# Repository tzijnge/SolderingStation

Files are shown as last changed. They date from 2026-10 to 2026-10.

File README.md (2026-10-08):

# SolderingStation

[WIO Terminal](https://wiki.seeedstudio.com/Wio_Terminal_Intro/) adaptation of the [Elektor Platino soldering station](https://www.elektormagazine.com/magazine/elektor-201507/27978)

## Development environment

### Tooling

- [Visual Studio Code](https://code.visualstudio.com/)
- [PlatformIO IDE extension](https://platformio.org/install/ide?install=vscode) for VS Code (recommended in `.vscode/extensions.json`)
  - Installs its own toolchain (GCC ARM, `pio` CLI, etc.) on first use — no separate Arduino IDE or ARM toolchain install needed
- [Teleplot](https://teleplot.fr/) VS Code extension (optional) — for live-plotting the PID tuning telemetry printed over serial, see [Telemetry / PID tuning](#telemetry--pid-tuning) below
- [KiCad 10](https://www.kicad.org/) — for the front panel PCB, see [Front panel](#front-panel) below

### Hardware target

- [Seeed WIO Terminal](https://wiki.seeedstudio.com/Wio_Terminal_Intro/) (SAMD51, Cortex-M4F)
- `atmelsam` platform, `board = seeed_wio_terminal`, `framework = arduino` (see `platformio.ini`)

### Libraries

Declared in `platformio.ini` under `lib_deps`, fetched automatically by PlatformIO on build:

- [LovyanGFX](https://github.com/lovyan03/LovyanGFX) — drives the 2.4" ILI9341 LCD (`#include <LovyanGFX.hpp>`, class `LGFX`), using genuine DMA-based SPI for speed. Needs `-D LGFX_AUTODETECT -D LGFX_WIO_TERMINAL` in `platformio.ini`'s `build_flags`, since PlatformIO's `seeed_wio_terminal` board definition doesn't define `ARDUINO_WIO_TERMINAL`, which LovyanGFX's autodetect normally keys off.
- [SparkFun_Qwiic_Twist_Arduino_Library](https://github.com/sparkfun/SparkFun_Qwiic_Twist_Arduino_Library) — driver for the Qwiic Twist rotary encoder, connected via a Grove-to-Qwiic cable on the WIO Terminal's Grove I2C port
- [ETL (Embedded Template Library)](https://github.com/ETLCPP/etl) — used throughout for containers/utilities in this interrupt-driven design
- [Arduino-PID-Library](https://github.com/br3ttb/Arduino-PID-Library) — drives the tip-temperature PID control loop

### Building and uploading

Build and upload using the PlatformIO sidebar in VS Code (project/build/upload icons in the PlatformIO toolbar), or the equivalent `pio run` / `pio run -t upload` commands from a PlatformIO Core CLI.

### Known build gotchas

- `Arduino.h` `#define`s `round(x)` as a macro, which breaks ETL's `etl::to_string`. Add `#undef round` right after `#include <Arduino.h>` and before any `etl/*` includes in any file that includes both.
- LovyanGFX's rotation numbering for this board is offset by 180° from the old TFT_eSPI-based fork this project used to use — call `tft.setRotation(1)` (not `3`) for correct upright landscape orientation.

## Hardware

### Inputs

- Three onboard buttons (`WIO_KEY_A`/`B`/`C`, pins 28/29/30). Physical left-to-right position does **not** match alphabetical pin naming — confirmed on-device: left = `WIO_KEY_C`, middle = `WIO_KEY_B`, right = `WIO_KEY_A`.
- [SparkFun Qwiic Twist](https://www.sparkfun.com/products/15083) rotary encoder, connected via Grove-to-Qwiic cable into the WIO Terminal's Grove I2C port (standard `Wire`, no special Qwiic-specific setup needed). Its INT pad is wired to `BCM21` (40-pin header physical position 40) — confirmed working. **Do not** wire it to `BCM2` (physical position 3): despite the Arduino pin table labeling it as a free, independent I2C bus, it shares a net at the PCB level with the Grove I2C bus and breaks the Twist's communication when wired, even before any new firmware is uploaded.
  - The Twist library never enables its own interrupt register (`TWIST_ENABLE_INTS`, `0x04`) — `setup()` writes it directly over raw I2C (`0x03`, encoder + button interrupt bits) to get the INT line to assert at all.
  - `twist.setIntTimeout(0)` is set to avoid the default ~250ms coalescing delay on rotation events, for a responsive display.

### Tip temperature sensing

Signal chain from the soldering tip's thermocouple to the ADC reading (see `TipTemperature.h`):

```
tip sensor (16uV/°C) -> PCB amplifier (gain 68000/150) -> ADC (12-bit, 3.3V ref, pin A3/BCM24/40-pin header pin 18)
```

### Heater and power supply

- The soldering iron's heating element measures ~2Ω and is rated 40W (implied design voltage ≈ 9–12V, not the 19V a laptop supply would suggest).
- Power supply: **12V, 5A** (not the originally-considered 19V/3A laptop brick, which was bench-tested and found both underpowered — couldn't supply the ~9.5A peak current the element draws at 19V without significant ripple — and would have driven the element to ~4.5x its rated power at full duty).
- The reverse-polarity protection diode on the supply input is a **Schottky** diode (not silicon) — its lower forward voltage drop (~0.2–0.3V vs. ~0.7V) leaves more of the supply's voltage headroom for the heater.
- PWM output pin: `BCM23`/A2.

⚠️ **Safety note:** at the time of writing, this firmware has no firmware-enforced maximum duty cap, no sensor fault-checking (e.g. a disconnected sensor reading as "too cold" and driving the PID to sustained high duty), and no hardware watchdog. Until these are implemented, do not leave the station heating unattended.

### Front panel

A PCB used as the enclosure's front panel (black soldermask, white silkscreen), KiCad 10 project in `hardware/frontpanel/`. It carries the mains switch, the WIO Terminal (plugged into a 40-pin header on the front), the Qwiic Twist knob (on the back, plugged into a socket) and the XLR socket for the iron. All routing is on the back layer, so nothing shows through the soldermask on the front.

The board is generated by `generate_frontpanel.py`. To adapt it to your own enclosure and parts, edit the constants at the top of the script and run it with the Python interpreter that comes with KiCad 10:

```
<KiCad install dir>/bin/python generate_frontpanel.py
```

The main parameters (all in mm, from the top-left corner as seen from the front):

- `PANEL_W`, `PANEL_H`, `PANEL_THICKNESS`, `SLOT_DEPTH` — panel size and how far it sits in the enclosure's slots.
- `SWITCH_X`, `WIO_X`, `KNOB_X`, `XLR_X` — horizontal position of each part; everything is centred vertically. The connectors, tracks and silkscreen follow.
- `SWITCH_HOLE_D`, `ENCODER_HOLE_D`, `XLR_HOLE_D`, `XLR_SCREW_DX` — cutouts for your particular parts.
- `BACK_CONN_POS`, `BACK_CONN_EXIT` — where the connector to the iron PCB sits and which way its cable leaves.
- `CREDITS`, `REPO_URL` — text and QR code on the back.

After regenerating, open the board in KiCad and run DRC. The script overwrites `frontpanel.kicad_pcb`, so either keep making changes in the script, or edit in KiCad and stop using the script.

The connector to the soldering iron PCB (J3, 4-pin JST-PH) — the iron PCB must use the same order:

| Pin | Signal | WIO |
|---|---|---|
| 1 | TEMP (tip temperature, ADC) | `A3`/`BCM24` |
| 2 | GND | |
| 3 | HEATER PWM | `BCM23` |
| 4 | 5V (powers the WIO) | |

A second 4-pin JST-PH (J4) brings out three spare GPIOs (`BCM7`, `BCM12`, `BCM16`) and GND for debugging.

Things to watch out for:

- The WIO's 40-pin header follows the Raspberry Pi pinout exactly. The pin table in the board's `variant.h` wrongly shows pin 17 as GND; it's 3.3V.
- The Twist's encoder is on its bottom side, so seen from the front its pin row is mirrored relative to SparkFun's drawings.
- The copper pours stay clear of the board edge and of the XLR and mains switch, so logic GND can't touch the earthed enclosure, the XLR chassis or mains.
- The panel must fill the enclosure's slots (2.2 mm here). A 2.0 mm board costs about four times as much as a 1.0 or 1.6 mm one, so here two identical 1.0 mm boards are stacked (`PANEL_THICKNESS` = 1.0): the back one carries the parts, the front one only shows its front side, and the parts' screws clamp them together. The 40-pin header then goes through both boards — use one with pins long enough to solder on the back of the back board.
- Have the fab leave its order number off the board (at JLCPCB: "Mark on PCB: Remove Mark", same price).

## Telemetry / PID tuning

`main.cpp` prints live PID tuning telemetry over `Serial` (115200 baud) in [Teleplot](https://teleplot.fr/)'s `>name:value` line format — install the Teleplot VS Code extension, point it at the board's serial port, and it plots `setpoint`, `measured`, `measuredFiltered`, `measuredAvg`, and `duty` live. This telemetry code (and the `TipTemperature::filteredValue()`/raw `value()` split it depends on) is marked `// TEMPORARY` in the source and intended to be removed once PID tuning is complete.

`TemperatureController`'s `Kp`/`Ki`/`Kd` gains are placeholders — this project has no characterized plant model (heater wattage, thermal mass, sensor lag), so they need on-device tuning: start with pure P, observe steady-state behavior, add `Ki` to remove steady-state error, and only add `Kd` afterward if overshoot still needs taming.

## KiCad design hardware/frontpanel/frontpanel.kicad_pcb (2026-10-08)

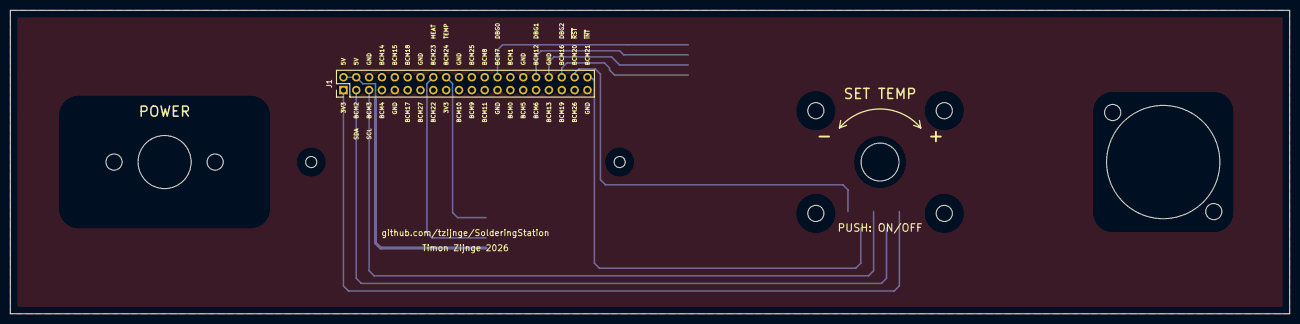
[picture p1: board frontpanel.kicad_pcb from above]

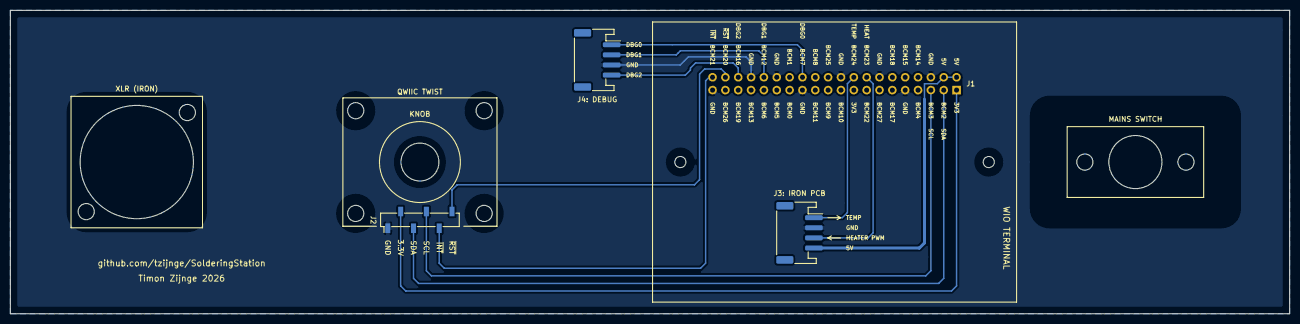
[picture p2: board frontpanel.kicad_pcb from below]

Board: 2 copper layers, 253.0 x 60.0 mm, 14 parts (3 on the bottom side), 12 nets.

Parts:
H1, H2: MountingHole_2.2mm_M2
H3, H4, H5, H6, H7, H8, H9, H10: MountingHole_3.2mm_M3
J1: PinHeader_2x20_P2.54mm_Vertical
J2: PinSocket_1x06_P2.54mm_Vertical_SMD_Pin1Left
J3, J4: JST_PH_S4B-PH-SM4-TB_1x04-1MP_P2.00mm_Horizontal

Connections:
+3V3: J1.1, J2.5
+5V: J1.2, J1.4, J3.4
DBG0: J1.26, J4.1
DBG1: J1.32, J4.2
DBG2: J1.36, J4.4
GND: J1.6, J1.9, J1.14, J1.20, J1.25, J1.30, J1.34, J1.39, J2.6, J3.2, J4.3
HEATER_PWM: J1.16, J3.3
I2C_SCL: J1.5, J2.3
I2C_SDA: J1.3, J2.4
TIP_ADC: J1.18, J3.1
TWIST_INT: J1.40, J2.2
TWIST_RST: J1.38, J2.1

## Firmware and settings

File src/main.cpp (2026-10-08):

#include <Arduino.h>
#include <LovyanGFX.hpp>
#include <Wire.h>
#include <SparkFun_Qwiic_Twist_Arduino_Library.h>
#include <etl/callback_timer_interrupt.h>
#include <etl/delegate.h>
#include <etl/function.h>
#include <etl/scheduler.h>

#include "adc/AdcInput.h"
#include "counter/CounterPwmOutput.h"
#include "tasks/EncoderTask.h"
#include "tasks/NotifyTask.h"
#include "temperature/SetpointDisplayTask.h"
#include "temperature/TemperatureController.h"
#include "temperature/TemperatureDisplay.h"
#include "temperature/TemperatureSetpoint.h"
#include "temperature/TipTemperature.h"
#include "temperature/TipTemperatureDisplayTask.h"

LGFX tft; // LGFX_AUTODETECT (platformio.ini build_flags) configures this for the WIO Terminal's exact ILI9341/SERCOM7/backlight setup automatically
TWIST twist;

// This panel is 320x240 in landscape (setRotation(1)). Each row's visual
// bounding box is 54px tall - not the raw 48px font 7 digit height, since
// the degree-C suffix's 'C' is bottom-aligned with the digits (see
// TemperatureDisplay::begin()) and sticks up 6px above the digit top.
// Centering two such rows with equal top margin/gap/bottom margin across
// the 240px height solves 3*M + 2*54 = 240, giving M = 44: margin 44, row
// top at y=50 (44+6, since the row's own visual top is y-6), row bottom at
// 98, another 44px gap, second row top at y=148, bottom at 196, then a
// final 44px margin to the bottom edge.
TemperatureDisplay setpointDisplay(tft, 50, TFT_GREEN); // button/encoder controlled
CounterPwmOutput pwmOutput(BCM23);

// The only place the setpoint's value, its 50..450 clamp, and the station's
// on/off state live. Neither producer below knows this type exists beyond
// what's bound into their delegates. Not driven by PWM directly (contrast
// with the old Counter this replaces) - temperatureController polls it
// once per ADC measurement cycle instead (see measureAndResume below);
// setpointDisplayTask polls it for the redraw (see below).
TemperatureSetpoint setpoint;

// onDiff/onPress bind directly to TemperatureSetpoint's own methods - no
// wrapper needed since the delegate signatures already match exactly.
// EncoderTask itself never sees the TemperatureSetpoint type.
EncoderTask encoderTask(twist, BCM21,
                        etl::delegate<void(int16_t)>::create<TemperatureSetpoint, &TemperatureSetpoint::diffSteps>(setpoint),
                        etl::delegate<void(void)>::create<TemperatureSetpoint, &TemperatureSetpoint::toggle>(setpoint));

// Each button needs a fixed argument (+-1 step) or no argument at all baked
// in, which a plain bound-member delegate can't express, hence these small
// lambdas rather than binding straight to TemperatureSetpoint::diffSteps/
// toggle. Like all etl::delegate use in this project, they must be named
// objects with program lifetime, never inline lambda literals (see
// NotifyTask for why).
auto decrementSetpoint = []() { setpoint.diffSteps(-1); };
auto toggleSetpoint = []() { setpoint.toggle(); };
auto incrementSetpoint = []() { setpoint.diffSteps(1); };
NotifyTask leftButtonTask(decrementSetpoint);
NotifyTask middleButtonTask(toggleSetpoint);
NotifyTask rightButtonTask(incrementSetpoint);

// Polls setpoint rather than observing it - see SetpointDisplayTask and
// TemperatureSetpoint's own comments for why the redraw is decoupled from
// whichever task (a button or the encoder) just changed the value.
SetpointDisplayTask setpointDisplayTask(setpoint, setpointDisplay);

// Raw 12-bit ADC reading (0..4095, VDDANA/3.3V reference - both are this
// board's defaults) on A3/BCM24/40-pin header pin 18, sampled once per
// 100ms cycle (see pauseForMeasurement/measureAndResume below - PWM is
// paused around each sample to keep its switching noise out of the
// reading), converted by tipTemperature into a whole-degree Celsius tip
// temperature (see temperature/TipTemperature.h for the sensor/amplifier/
// ADC math). Not built on a Counter/Setpoint-style class - neither a raw
// ADC sample nor a temperature reading has diff/toggle/clamp semantics, so
// that abstraction doesn't fit here.
//
// temperatureDisplayTask (declared after swTimer below, alongside the
// other tasks) polls tipTemperature and redraws on its own turn in the
// scheduler - deliberately decoupled from onAdcSample() itself, since
// that redraw is a slow (~17ms, see project notes) SPI write and
// measureAndResume() needs pwmOutput.resume() to run right after
// sampling, not after whatever a redraw happens to cost that cycle.
TemperatureDisplay temperatureDisplay(tft, 148, TFT_MAGENTA);
TipTemperature tipTemperature;
AdcInput adcInput(A3);

// Turns (setpoint, tipTemperature) into a PWM duty each measurement cycle
// (see measureAndResume below) via br3ttb/Arduino-PID-Library - see
// TemperatureController.h for the on/off handling and why compute()'s
// 100ms cadence matters. Kp/Ki/Kd are placeholders: this project has no
// characterized plant model (heater wattage, thermal mass, sensor lag), so
// these need on-device tuning. Full power heats the tip at ~70-75 degrees/s
// (measured: 50 -> 350 in under 5s), i.e. ~7 degrees per 100ms sample, so overshoot is dominated by lag (the
// EMA filter in TipTemperature, heat still flowing into the sensor) - a
// small Kd (~1, acting on the measurement's rate of change) is the next
// knob if overshoot needs taming. Kp was lowered from 20 to 10 after
// FILTER_ALPHA went 0.3 -> 0.5: with less filter lag, Kp=20 gave a fast,
// near 0<->255 duty oscillation around the setpoint for a few seconds -
// too much gain for the remaining heater-to-sensor lag. If that persists,
// lower Kd next (it sees more noise with the lighter filter).
TemperatureController temperatureController(setpoint, /*Kp*/ 10.0, /*Ki*/ 2.0, /*Kd*/ 0.5);

// Guards register_timer()/start()/stop() (called from setup(), i.e. normal
// code) against a concurrent SysTick interrupt calling tick() mid-update -
// tick() itself doesn't need guarding since it *is* that interrupt.
struct SysTickGuard {
  SysTickGuard() { NVIC_DisableIRQ(SysTick_IRQn); }
  ~SysTickGuard() { NVIC_EnableIRQ(SysTick_IRQn); }
};

// A 100ms repeating PWM-pause, a 5ms one-shot ADC measurement, and a 100ms
// repeating telemetry print (see pauseForMeasurement/measureAndResume/
// printTelemetry below) - this is just where this project's software
// timers live. tick() is called with a 1ms count from sysTickHook() below,
// so periods registered on this are in milliseconds.
etl::callback_timer_interrupt<3, SysTickGuard> swTimer;

// pwmOutput switching is a noise source for the ADC reading, so each
// measurement cycle pauses it first: a 100ms repeating timer pauses PWM
// and arms a 5ms one-shot (registered once in setup(), non-repeating,
// just re-started here each cycle) to give the switching noise time to
// settle before the actual sample is taken and PWM resumed.
etl::timer::id::type measureTimerId; // assigned once in setup()

// TEMPORARY: 2-second moving average of the measured temperature, for the
// Teleplot tuning plot (see printTelemetry() below) - smooths out sensor
// noise so the underlying trend is easier to read. printTelemetry() runs
// every 100ms, so 2000/100 = 20 samples. movingAvgCount ramps up from 0 to
// MOVING_AVG_SAMPLES so the average isn't biased low by not-yet-written
// zeros in the buffer during the first 2 seconds after boot.
constexpr size_t MOVING_AVG_SAMPLES = 20;
float movingAvgBuffer[MOVING_AVG_SAMPLES] = {};
size_t movingAvgIndex = 0;
size_t movingAvgCount = 0;
float movingAvgSum = 0.0f;

// TEMPORARY: last duty computed by measureAndResume(), cached purely so
// printTelemetry() (a separate task - see below) can report it without
// touching the timing-critical measurement cycle itself.
uint8_t lastDuty = 0;

auto pauseForMeasurement = []() {
  pwmOutput.pause();
  swTimer.start(measureTimerId);
};
auto measureAndResume = []() {
  adcInput.sample();
  uint8_t duty = temperatureController.compute(tipTemperature.filteredValue());
  lastDuty = duty;
  // Still paused here - onCounterChanged() only updates lastValue without
  // writing to the pin (see CounterPwmOutput::pause()), so the new duty
  // takes effect exactly when resume() un-pauses it below.
  pwmOutput.onCounterChanged(duty);
  pwmOutput.resume();
};

// TEMPORARY: PID-tuning telemetry, in Teleplot's >name:value format
// (https://teleplot.fr/) - install the "teleplot" VS Code extension, point
// it at this board's serial port, and it plots setpoint/measured/
// measuredAvg/duty live. One line per variable rather than combining them
// with commas - more reliably parsed.
//
// Deliberately a separate task from measureAndResume(), on its own 100ms
// timer, rather than printing inline there - Serial.print() can block
// (e.g. if the USB CDC buffer fills because nothing's draining it fast
// enough), and measureAndResume() needs pwmOutput.resume() to run
// promptly and predictably every cycle, same reasoning as why display
// redraws are decoupled from it (see TipTemperatureDisplayTask). A stalled
// print here can no longer delay that at all, or desynchronize the pause/
// resume timing against the 5ms measurement window.
//
// Remove this whole task (and lastDuty/movingAvg* above) once tuning is
// done.
auto printTelemetry = []() {
  if (movingAvgCount < MOVING_AVG_SAMPLES) {
    movingAvgCount++;
  } else {
    movingAvgSum -= movingAvgBuffer[movingAvgIndex];
  }
  movingAvgBuffer[movingAvgIndex] = tipTemperature.value();
  movingAvgSum += movingAvgBuffer[movingAvgIndex];
  movingAvgIndex = (movingAvgIndex + 1) % MOVING_AVG_SAMPLES;

  // 0 while off (setpoint.value() itself still holds the real value
  // internally, for resume - this only affects what's plotted), so the
  // plot clearly shows "no active setpoint" at startup and on every
  // off-toggle instead of a misleading stale/preserved number.
  Serial.print(">setpoint:"); Serial.println(setpoint.isOn() ? setpoint.value() : 0);
  Serial.print(">measured:"); Serial.println(tipTemperature.value());
  Serial.print(">measuredFiltered:"); Serial.println(tipTemperature.filteredValue());
  Serial.print(">measuredAvg:"); Serial.println(movingAvgSum / movingAvgCount);
  Serial.print(">duty:"); Serial.println(lastDuty);
};
NotifyTask pwmPauseTask(pauseForMeasurement);
NotifyTask adcSampleTask(measureAndResume);
NotifyTask telemetryTask(printTelemetry);
TipTemperatureDisplayTask temperatureDisplayTask(tipTemperature, temperatureDisplay);

// "Single" (not "multiple"): processes at most one unit of work per task
// per round before moving to the next, so a task whose task_request_work()
// stays true for an extended period (e.g. EncoderTask while the Twist's
// button is held) can't starve the tasks after it in the list. setpoint,
// temperatureController and pwmOutput aren't scheduler tasks at all - each
// update happens synchronously, inline, as part of the producing task's
// task_process_work() call.
etl::scheduler<etl::scheduler_policy_sequential_single, 9> scheduler;

// Runs whenever a full scheduler pass finds no task with work. yield() is
// a no-op on this build (USBCON, not TinyUSB - USB is interrupt-driven and
// doesn't need it), kept only in case some future library overrides that
// weak hook. __WFI() sleeps the CPU until the next interrupt (a button
// press, an encoder interrupt, the 1ms SysTick tick, or ...).
void onIdle() {
  yield();
  __WFI();
}

etl::function_fv<onIdle> idleCallback;

// WIO_KEY_A/B/C are the three top buttons (variant.h). Confirmed on-device:
// left = WIO_KEY_C, middle = WIO_KEY_B, right = WIO_KEY_A.
void onLeftButton() { leftButtonTask.notify(); }
void onMiddleButton() { middleButtonTask.notify(); }
void onRightButton() { rightButtonTask.notify(); }

// Twist's INT pad wired to BCM21 (40-pin header, physical position 40).
void onEncoderInterrupt() {
  // Intentionally empty: EncoderTask::task_request_work() reads the pin
  // level directly. This callback exists only so the attached interrupt
  // wakes the CPU from __WFI() sleep promptly.
}

// Called from the real SysTick_Handler, before the Arduino core's own
// default handler (see hooks.c) - this is what actually drives swTimer,
// replacing millis()/delay()-based polling for anything this project
// schedules on its own. Returning false lets the default handler still run
// afterward so millis()/micros()/delay() keep working too (cheap to leave
// alone, and some library init code still uses delay() internally), but
// nothing in this project's own logic depends on them anymore.
extern "C" int sysTickHook(void) {
  swTimer.tick(1);
  return 0;
}

void setup() {
  Serial.begin(115200); // for the Teleplot telemetry in printTelemetry() - see there

  Wire.begin();
  Wire.setClock(400000); // fast-mode I2C, keeps polling latency low

  tft.begin();
  // LovyanGFX's rotation numbering doesn't match Seeed_GFX's for this panel -
  // its own WIO Terminal autodetect (LGFX_AutoDetect_SAMD51.hpp) calibrates
  // rotation 1 as this board's correct upright landscape orientation.
  tft.setRotation(1);
  tft.fillScreen(TFT_BLACK);
  tft.setTextColor(TFT_WHITE, TFT_BLACK);
  tft.setTextSize(2);
  tft.setCursor(10, 10);

  if (!twist.begin()) {
    tft.println("Qwiic Twist not found!");
    while (true) {
      delay(1000);
    }
  }

  // The Twist library never writes TWIST_ENABLE_INTS (register 0x04,
  // bit0 = encoder interrupt enable, bit1 = button interrupt enable - see
  // enableInterruptEncoderBit/enableInterruptButtonBit in the library's
  // header) - no public method touches it, so it's whatever the module's
  // firmware defaulted to. Force both bits on directly over I2C.
  Wire.beginTransmission(QWIIC_TWIST_ADDR);
  Wire.write(0x04); // TWIST_ENABLE_INTS
  Wire.write(0x03); // bit0 encoder int enable, bit1 button int enable
  Wire.endTransmission();

  // Default firmware waits ~250ms after turning stops before firing the
  // movement interrupt (coalesces rapid turning into one interrupt), which
  // made the display update in laggy bursts. Try to get closer to
  // real-time by minimizing that wait.
  twist.setIntTimeout(0);

  // Buttons pull the pin to GND when pressed, so use the internal
  // pull-up and trigger on the falling edge.
  pinMode(WIO_KEY_A, INPUT_PULLUP);
  pinMode(WIO_KEY_B, INPUT_PULLUP);
  pinMode(WIO_KEY_C, INPUT_PULLUP);

  attachInterrupt(digitalPinToInterrupt(WIO_KEY_A), onRightButton, FALLING);
  attachInterrupt(digitalPinToInterrupt(WIO_KEY_B), onMiddleButton, FALLING);
  attachInterrupt(digitalPinToInterrupt(WIO_KEY_C), onLeftButton, FALLING);

  // Twist's INT line is open-drain, active low - same pull-up/FALLING
  // pattern as the buttons.
  pinMode(BCM21, INPUT_PULLUP);
  attachInterrupt(digitalPinToInterrupt(BCM21), onEncoderInterrupt, FALLING);

  // Text datum is set explicitly by TemperatureDisplay itself on every draw
  // (TR_DATUM for the number, TL_DATUM for the degree-C suffix), not relied
  // on as ambient state here.
  tft.setFont(&fonts::Font7); // 0-9, ':', '-', '.'
  tft.setTextSize(1);
  tft.setTextPadding(TemperatureDisplay::NUMBER_PADDING); // shared with TemperatureDisplay's suffix positioning - see its header

  pwmOutput.begin();
  pwmOutput.onCounterChanged(0); // defined-off PWM state from boot, matching setpoint/temperatureController's initial off state
  setpointDisplay.begin(); // draws the static degree-C suffix once

  analogReadResolution(12); // 0..4095 instead of the default 10-bit 0..1023
  temperatureDisplay.begin(); // draws the static degree-C suffix once
  adcInput.add_observer(etl::delegate<void(uint16_t)>::create<TipTemperature, &TipTemperature::onAdcSample>(tipTemperature));
  adcInput.sample(); // seeds tipTemperature; temperatureDisplayTask's first poll draws the initial number

  // Registered but not started - only re-started by pauseForMeasurement,
  // repeating=false so it fires exactly once per arm.
  measureTimerId = swTimer.register_timer(
      etl::delegate<void(void)>::create<NotifyTask, &NotifyTask::notify>(adcSampleTask), 5U, false);

  etl::timer::id::type pwmPauseTimerId = swTimer.register_timer(
      etl::delegate<void(void)>::create<NotifyTask, &NotifyTask::notify>(pwmPauseTask), 100U, true);
  swTimer.start(pwmPauseTimerId);

  // TEMPORARY: drives printTelemetry() - see its own comment for why this
  // is a separate task/timer rather than being inline in measureAndResume().
  etl::timer::id::type telemetryTimerId = swTimer.register_timer(
      etl::delegate<void(void)>::create<NotifyTask, &NotifyTask::notify>(telemetryTask), 100U, true);
  swTimer.start(telemetryTimerId);

  swTimer.enable(true);

  scheduler.add_task(encoderTask);
  scheduler.add_task(leftButtonTask);
  scheduler.add_task(middleButtonTask);
  scheduler.add_task(rightButtonTask);
  scheduler.add_task(setpointDisplayTask);
  scheduler.add_task(pwmPauseTask);
  scheduler.add_task(adcSampleTask);
  scheduler.add_task(telemetryTask);
  scheduler.add_task(temperatureDisplayTask);
  scheduler.set_idle_callback(idleCallback);

  // Short startup beep, last in setup() so it also signals that init
  // succeeded (e.g. the Twist was found). Deliberately NOT tone(): the Seeed
  // core's tone() runs on TC0, which LovyanGFX's WIO Terminal autodetect
  // already uses for the LCD backlight PWM (Light_WioTerminal) - tone()
  // resets TC0 and disables it when done, turning the backlight off.
  // analogWrite() on WIO_BUZZER uses TCC0 (CH4) instead, which nothing else
  // here touches. Blocking, but it's a one-off 100ms at boot.
  analogWrite(WIO_BUZZER, 128);
  delay(100);
  analogWrite(WIO_BUZZER, 0);
}

void loop() {
  // Blocks here running the cooperative task loop for as long as the
  // scheduler is running (i.e. forever, unless something calls
  // scheduler.exit_scheduler()).
  scheduler.start();
}

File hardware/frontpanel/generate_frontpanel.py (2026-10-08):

"""Generates the initial front-panel board: frontpanel.kicad_pcb (+ project file).

Run with the Python interpreter bundled with KiCad 10 (it provides the pcbnew
module), found in the bin directory of the KiCad installation:

    <KiCad install dir>/bin/python generate_frontpanel.py

This is a one-shot starting point. Once the board has been edited by hand in
KiCad, don't re-run it - it overwrites frontpanel.kicad_pcb.

All coordinates below are in mm, in panel coordinates: origin at the top-left
corner of the panel, x to the right, y down, as seen from the FRONT (user side).
"""
import math
import os

import pcbnew as p

HERE = os.path.dirname(os.path.abspath(__file__))
PCB_PATH = os.path.join(HERE, "frontpanel.kicad_pcb")
FP_DIR = os.environ.get(
    "KICAD10_FOOTPRINT_DIR",
    os.path.normpath(os.path.join(os.path.dirname(p.__file__), "..", "..", "..", "share", "kicad", "footprints")),
)

# Where the panel sits on the KiCad sheet
SHEET_X, SHEET_Y = 20.0, 40.0

# --- Panel -------------------------------------------------------------------
PANEL_W, PANEL_H = 253.0, 60.0
PANEL_THICKNESS = 1.0         # two identical boards are stacked to fill the 2.2 mm slots
SLOT_DEPTH = 2.0            # hidden in the enclosure slots, all four edges assumed
COPPER_EDGE_CLEARANCE = 1.5 # keeps logic GND away from the (PE-earthed) enclosure
CY = PANEL_H / 2            # common vertical centre line

# --- Part centres (x), left to right ------------------------------------------
# WIO towards the switch and the XLR towards the right edge, leaving ~30 mm of
# free space on either side of the Twist board (room for the debug connector)
SWITCH_X = 30.5
WIO_X = 90.0
KNOB_X = 172.0
XLR_X = 228.0

# --- Mains push button ------------------------------------------------------------
# ASSUMPTION: the 10 mm round cap is what passes through the panel
SWITCH_HOLE_D = 10.5
SWITCH_SCREW_DX = 10.0        # two M3 screws, 20 mm apart horizontally
SWITCH_KEEPOUT_MARGIN = 8.0   # no copper within this distance of the mains part
KEEPOUT_CORNER_RADIUS = 4.0   # rounded corners of the copper-free areas (switch, XLR)
# Copper-free circle around the WIO and Twist mounting holes, so a screw head,
# washer or spacer can't reach the copper even if it scratches the soldermask:
# typical pan head + washer, plus margin
SCREW_KEEPOUT_D = {"M2": 6.0, "M3": 8.0}

HALF_PITCH = 2.54 / 2         # half the 40-pin header pitch

# --- WIO Terminal (from Seeed's back-cover drawing, v3.0) ----------------------
WIO_BODY = (72.0, 57.0)
WIO_SCREW_DX = 30.5          # two M2 holes at mid height, +/-30.5 mm from centre
WIO_HEADER_DY = -15.5        # 40-pin header centre, towards the top edge
# Verified on the device: seen from the front, pin 1 is bottom-left, pin 2 top-left;
# odd pins are the bottom row.
WIO_PIN1_LEFT = True
WIO_ODD_ROW_TOP = False

# --- SparkFun Qwiic Twist (from SparkFun's board file) ------------------------
# Hangs behind the panel, encoder towards the panel. Its encoder has no threaded
# bushing, so the board is held by 4 M3 screws through the panel (with spacers
# between panel and Twist); the socket carries the signals. The encoder sits on
# the Twist's BOTTOM side (SW1 is mirrored in SparkFun's board file), so seen
# from the front we look at the Twist's bottom: SparkFun's top view mirrored
# left-right.
TWIST_BOARD = (30.48, 25.4)       # encoder is in the centre of the board
TWIST_HOLE_DX, TWIST_HOLE_DY = 12.7, 10.16
TWIST_PIN_ROW_DY = 11.43          # pin row below the encoder
# Pin row in SparkFun's top view, left to right (x = 8.89 ... 21.59 mm);
# reversed below to get the order as seen from the front.
_TWIST_PINS_TOP_VIEW = ["GND", "+3V3", "I2C_SDA", "I2C_SCL", "TWIST_INT", "TWIST_RST"]
_TWIST_LABELS_TOP_VIEW = ["GND", "3.3V", "SDA", "SCL", "~{INT}", "~{RST}"]  # silkscreen, ~{} = overbar
TWIST_PINS = _TWIST_PINS_TOP_VIEW[::-1]
TWIST_PIN_LABELS = _TWIST_LABELS_TOP_VIEW[::-1]
ENCODER_HOLE_D = 7.5              # PLACEHOLDER - clearance for the 6 mm shaft (no bushing)

# --- XLR 3-pin female ------------------------------------------------------------
XLR_HOLE_D = 22.4             # body measured 22 mm
# M3 holes top-left and bottom-right: 28 mm apart centre to centre, each 10 mm
# horizontally from the (horizontally centred) middle pin -> 20 mm apart in x,
# sqrt(28^2 - 20^2) = 19.6 mm apart in y.
XLR_SCREW_DX = 10.0
XLR_SCREW_DY = (28.0 ** 2 - (2 * XLR_SCREW_DX) ** 2) ** 0.5 / 2
XLR_SCREWS = [(-XLR_SCREW_DX, -XLR_SCREW_DY), (XLR_SCREW_DX, XLR_SCREW_DY)]
# The bottom-right screw connects to the connector chassis, so the flange and
# the screws/nuts must not touch panel copper: no copper under the whole area.
XLR_KEEPOUT_HALF = max(XLR_SCREW_DX, XLR_SCREW_DY) + 4.0

# --- Connector to the soldering iron PCB (4-pin JST-PH, SMD, back side) ---------
# Side entry (S4B-PH-SM4-TB): the cable leaves parallel to the panel, here to the
# right as seen from the front - towards the Twist/XLR, away from the mains button.
BACK_CONN_POS = (WIO_X + 6.0, 44.0)  # behind the WIO, well left of the Twist for the cable
BACK_CONN_EXIT = (1, 0)               # cable exit direction (x, y), panel coordinates
# pin: (net, silkscreen label); GND between the heater PWM and the tip ADC signal.
# Order matches the routing: the tracks arrive from the header, left to right,
# as 5V, HEAT, TEMP, so pin 1 (top) is TEMP and pin 4 (bottom) is 5V.
BACK_CONN_PINS = {1: ("TIP_ADC", "TEMP"), 2: ("GND", "GND"), 3: ("HEATER_PWM", "HEATER PWM"), 4: ("+5V", "5V")}
# Signal direction arrows next to the labels: +1 = out through the cable (to the
# soldering iron PCB), -1 = in from the cable (to the WIO)
BACK_CONN_ARROWS = {"HEATER_PWM": +1, "TIP_ADC": -1}
BACK_CONN_TITLE = "J3: IRON PCB"

# --- Debug connector (same 4-pin JST-PH, back side) -------------------------------
# Between the WIO and the Twist, near the top edge, so the cable (to the right)
# passes above the Twist board. Its tracks come over the top of the header,
# above RST, from unused top-row pins at the header's right end.
RST_OVER_Y = -1.63      # RST's run over pin 40, relative to the top header row
DEBUG_PITCH = 1.2       # between the nested debug tracks, above RST
_debug_top_track_y = CY + WIO_HEADER_DY - 2.54 / 2 + RST_OVER_Y - 4 * DEBUG_PITCH
# x: labels clear of the WIO outline; y: pin 1 (3 mm above the centre) in line
# with the highest debug track
DEBUG_CONN_POS = (WIO_X + WIO_BODY[0] / 2 + 10.0, _debug_top_track_y + 3.0)
DEBUG_CONN_EXIT = (1, 0)
# pin: (net, silkscreen label, WIO header pin). Order matches the routing (no
# crossings): the further left the header pin, the higher the connector pin.
DEBUG_CONN_PINS = {1: ("DBG0", "DBG0", 26), 2: ("DBG1", "DBG1", 32),
                   3: ("GND", "GND", 34), 4: ("DBG2", "DBG2", 36)}
DEBUG_CONN_TITLE = "J4: DEBUG"
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

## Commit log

2026-07-03 Soldering station * Initial commit
2026-07-03 Soldering station * Added PWM * Refactoring
2026-07-04 Soldering station * Refactoring
2026-07-04 Soldering station * Added timers
2026-07-06 Soldering station * Added reading and display of soldering tip temperature
2026-07-06 Soldering station * Forgotten files
2026-07-06 Soldering station * 5ms pause before ADC measurement * Some refactoring and optimization
2026-07-07 Soldering station * Moved to LovyanGFX to drive the display faster and use its fonts * Removed debug stuff
2026-07-08 Soldering station * Removed 1 second counter * Add PID control of the tip temperature (Only P for now) * Display now shows set temperature and actual temperature
2026-07-15 Soldering station * Added telemtery and some filtering
2026-09-28 Soldering Station * Added front panel design
    [frontpanel.kicad_pcb]
2026-10-08 Soldering Station * Panel thickness 1mm * Larger QR code
    [frontpanel.kicad_pcb]
2026-10-08 Soldering Station * Short beep at startup * Improved control settings * Improved temperature stability on display
    [TipTemperature.h, main.cpp]
2026-10-28 #1 Hard over-temperature cutoff (#23)
    * Add SafetyMonitor: cut the heater when the unfiltered tip temperature
    exceeds OVER_TEMPERATURE_LIMIT_C (450C), checked every 100ms measurement
    cycle before the PWM duty is applied (independent of the PID)
    * Add StationFsm (etl::fsm) with Off/On/Fault states as the single place
    deciding what inputs mean and whether the heater may run;
    Rotate/Press/FaultDetected events replace the direct setpoint bindings
    of the encoder and buttons (diagram in docs/state-machine.md)
    * Latch the fault until the tip is below the limit and the knob is
    pressed; acknowledging always lands in Off, so heating again needs a
    deliberate second press
    * Add full-screen fault screen: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
2026-10-28 Soldering station * Commit message tooling
2026-10-30 Soldering station * start-issue skill: draft the plan inline; have the Plan agent review it first for safety-critical or cross-cutting issues, or on request
2026-11-01 #2 Thermal runaway detection (#25)
    * Add ThermalRunaway fault: duty >= 200 for 3s while the tip reads below
    150C without rising at least 20C (catches a shorted sensor, which reads
    ~16C and gets full power; the absolute 150C arming limit avoids false
    trips on a ground plane at working temperature and still works at the
    50C minimum setpoint)
    * Add HeaterSaturated fault: duty >= 200 for 15s without a break at any
    temperature (backstop for a sensor that fails while the tip is hot,
    which looks like ground-plane soldering; real soldering never gets near
    the duty threshold - duty peaks around 110 even when desoldering a
    heatsink - so the limit only needs margin over a heat-up from cold at
    full powe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
2026-11-01 Soldering station * Add REGRESSION_TESTS.md: manual on-device regression tests grouped by feature (startup, input, display, temperature measurement, heater control, safety faults, beeps, panic, telem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
2026-11-03 #24 Remote control and telemetry via LotusRPC (#26)
    * Add a LotusRPC server on the USB serial port, defined in
    rpc/soldering_station.lrpc.yaml, with services input, status and
    telemetry
    * Add remote inputs (press, rotate, button left/middle/right) that go
    through the same delegates and button tasks as the real knob and
    buttons, so limits and fault latching apply unchanged; like the knob, a
    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
2026-11-07 #3 Tip sensor fault detection (#27)
    * Show "Tip above 450C or missing" for the over-temperature fault (a tip
    disconnected from a connected cable can pick up enough mains hum to
    swing to the top of the ADC range and trip the existing single-sample
    over-temperature check, but only depending on cable and environment, so
    this is not a reliable missing-tip check)
    * Add no separate sensor fault, and document why in SafetyMonitor.h and
    state-machine.md (a cold tip reads raw 0..28 and exactly 0 in about 5%
    of the samples, so a low-reading check would false-trip; a bare
    connector's pickup looks like a warm tip; reliable detection needs a
    hardware change)
    * Add tools/capture.py: read the telemetry str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
